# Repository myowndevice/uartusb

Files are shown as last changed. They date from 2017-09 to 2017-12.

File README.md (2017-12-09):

Данный репозитарий содержит информацию по прибору USB \ Serial
Если вы будете скачивать файлы через web не забудьте скачать общую папку Kicadlib

Если вы решили заняться электроникой, то вам просто необходим USB-Serial конвертер.
Вы его можете сделать самостоятельно по данной [инструкции](http://myowndevice.ru/index.php/pribory/item/7-usb-uart-konverter).

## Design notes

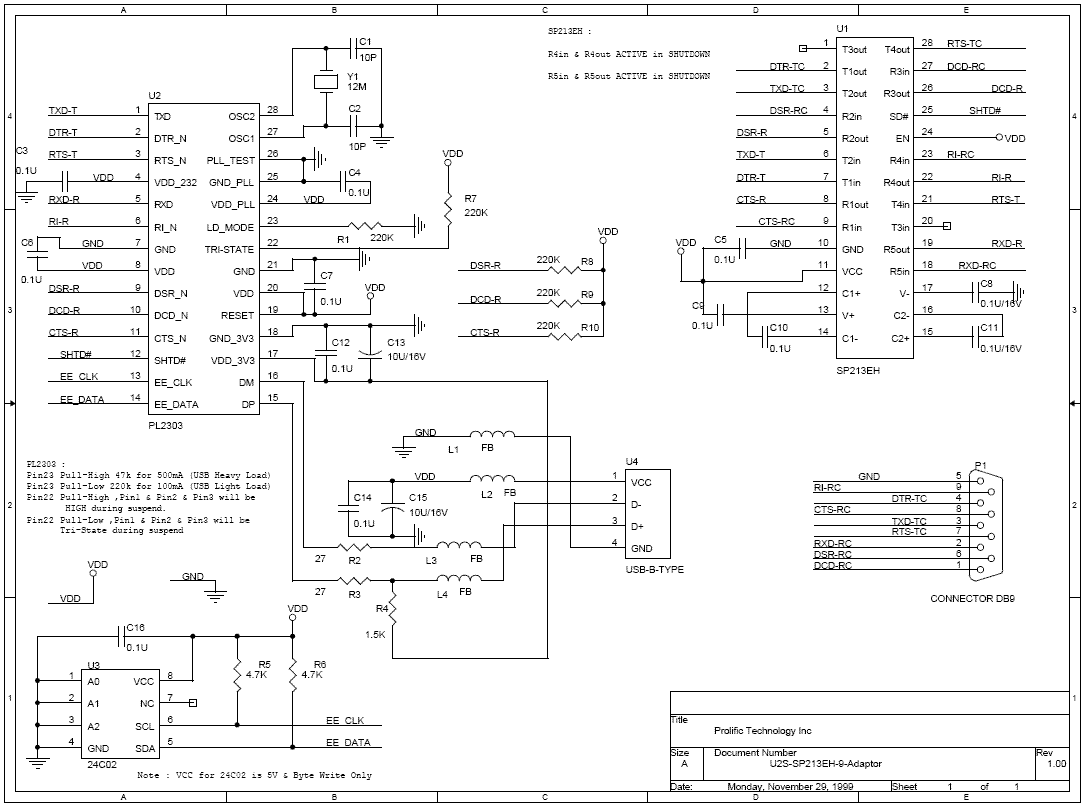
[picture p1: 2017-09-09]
datasheets/pl2303_75476858.gif

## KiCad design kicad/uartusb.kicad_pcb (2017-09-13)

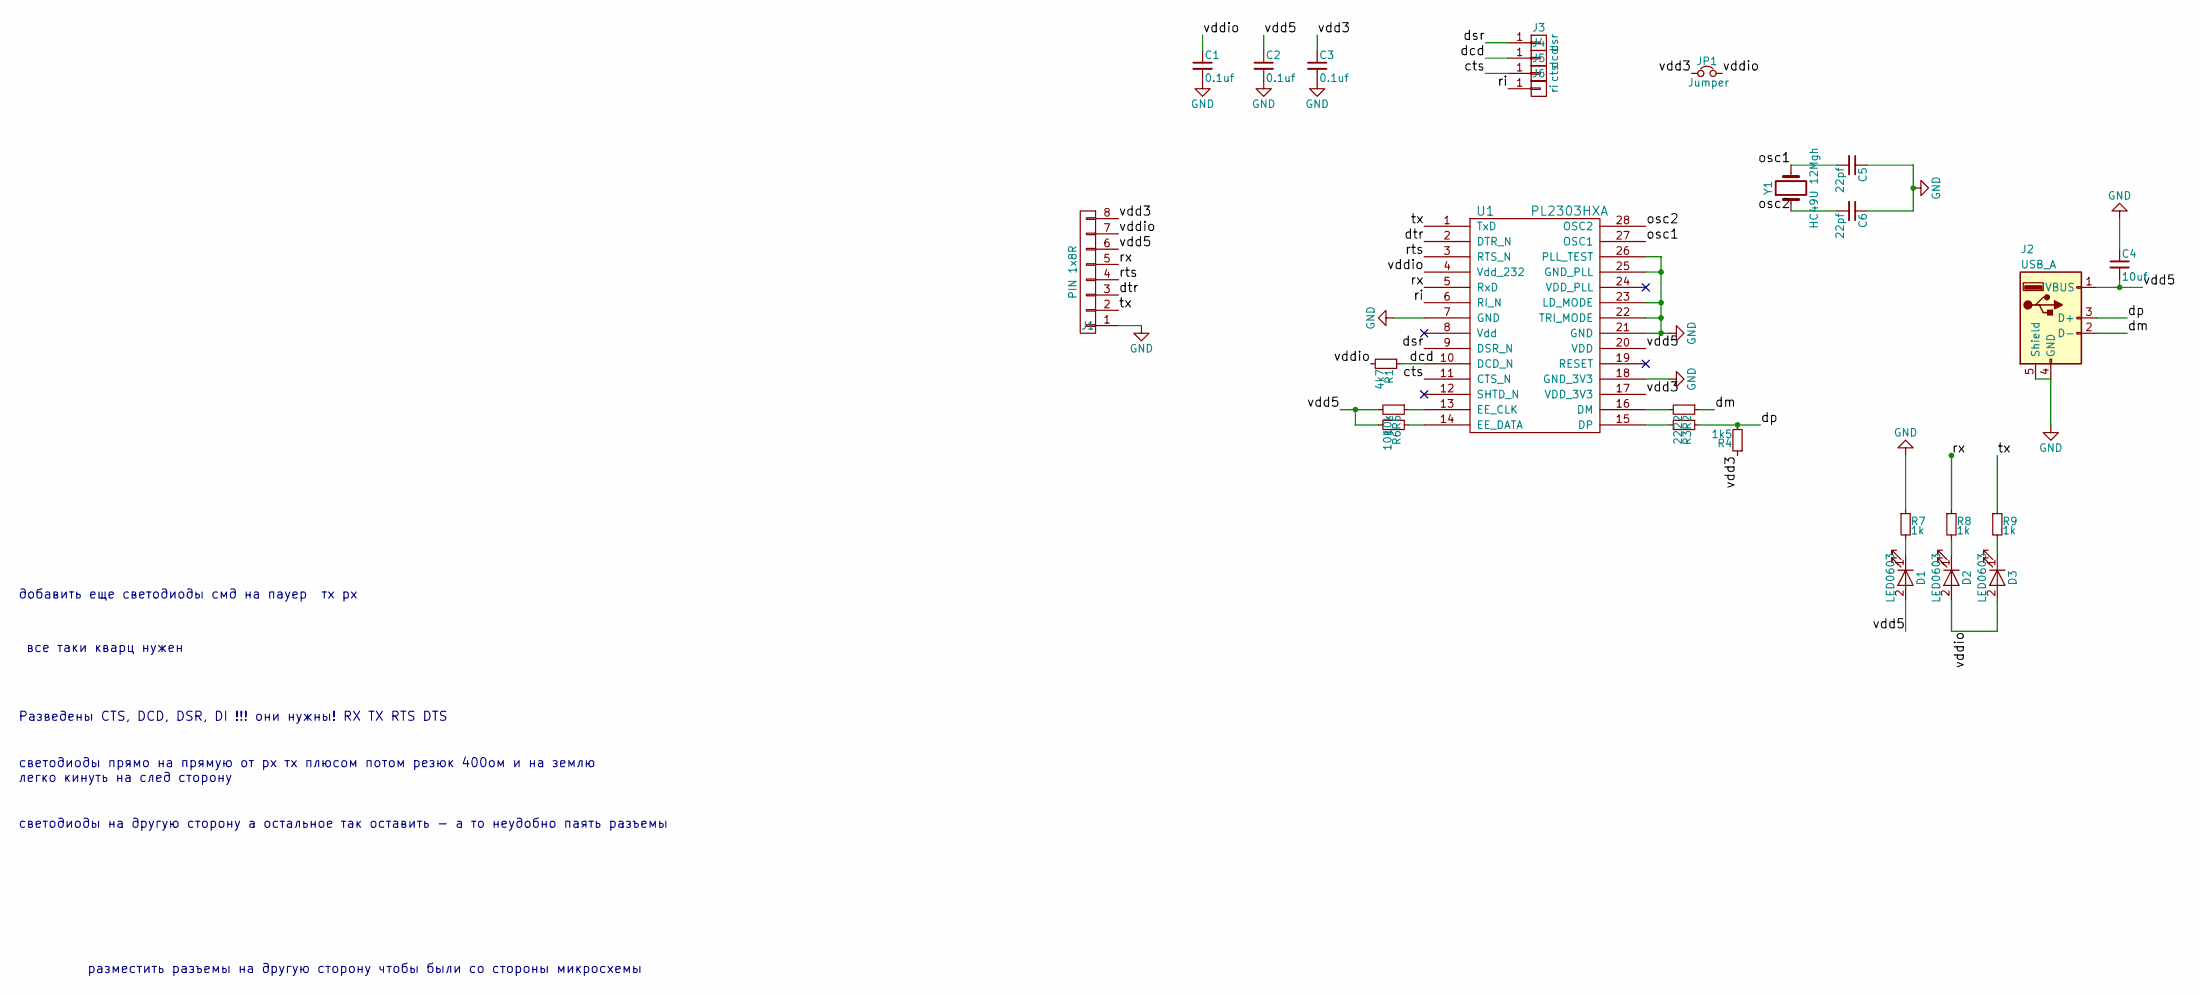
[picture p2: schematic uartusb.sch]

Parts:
C1, C2, C3: 0.1uf; C_0603_HandSoldering
C4: 10uf; R_0805_HandSoldering
C5, C6: 22pf; C_0603_HandSoldering
D1, D2, D3: LED0603; LED_0603_HandSoldering
J1: PIN 1x8R; Pin_Header_Angled_1x08_Pitch2.54mm
J2: USB_A; USB_A_male
J3: dsr; wirepadme
J4: dcd; wirepadme
J5: cts; wirepadme
J6: ri; wirepadme
JP1: Jumper; Pin_Header_Straight_1x02_Pitch2.54mm
R1: 4k7; R_0603_HandSoldering
R2, R3: 22; R_0603_HandSoldering
R4: 1k5; R_0603_HandSoldering
R5, R6: 10k; R_0603_HandSoldering
R7, R8, R9: 1k; R_0603_HandSoldering
U1: PL2303HXA; SSOP-28_5.3x10.2mm_Pitch0.65mm
Y1: HC49U 12Mgh; Crystal_HC49-4H_Vertical

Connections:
/cts: J5.1, U1.11 (CTS_N)
/dcd: J4.1, R1.1, U1.10 (DCD_N)
/dm: J2.2 (D-), R2.1
/dp: J2.3 (D+), R3.1, R4.2
/dsr: J3.1, U1.9 (DSR_N)
/dtr: J1.3, U1.2 (DTR_N)
/osc1: C5.2, U1.27 (OSC1), Y1.2
/osc2: C6.2, U1.28 (OSC2), Y1.1
/ri: J6.1, U1.6 (RI_N)
/rts: J1.4, U1.3 (RTS_N)
/rx: J1.5, R8.1, U1.5 (RxD)
/tx: J1.2, R9.1, U1.1 (TxD)
/vdd3: C3.1, J1.8, JP1.1, R4.1, U1.17 (VDD_3V3)
/vdd5: C2.1, C4.2, D1.2 (A), J1.6, J2.1 (VBUS), R5.2, R6.2, U1.20 (VDD)
/vddio: C1.1, D2.2 (A), D3.2 (A), J1.7, JP1.2, R1.2, U1.4 (Vdd_232)
GND: C1.2, C2.2, C3.2, C4.1, C5.1, C6.1, J1.1, J2.4 (GND), J2.5 (Shield), R7.1, U1.7 (GND), U1.18 (GND_3V3), U1.21 (GND), U1.22 (TRI_MODE), U1.23 (LD_MODE), U1.25 (GND_PLL), U1.26 (PLL_TEST)
unnamed: D1.1 (K), R7.2
unnamed: D2.1 (K), R8.2
unnamed: D3.1 (K), R9.2
unnamed: R2.2, U1.16 (DM)
unnamed: R3.2, U1.15 (DP)
unnamed: R5.1, U1.13 (EE_CLK)
unnamed: R6.1, U1.14 (EE_DATA)

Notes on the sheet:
добавить еще светодиоды смд на пауер тх рх
разместить разъемы на другую сторону чтобы были со стороны микросхемы
светодиоды на другую сторону а остальное так оставить - а то неудобно паять разъемы
светодиоды прямо на прямую от рх тх плюсом потом резюк 400ом и на землю легко кинуть на след сторону
все таки кварц нужен
Разведены CTS, DCD, DSR, DI !!! они нужны! RX TX RTS DTS

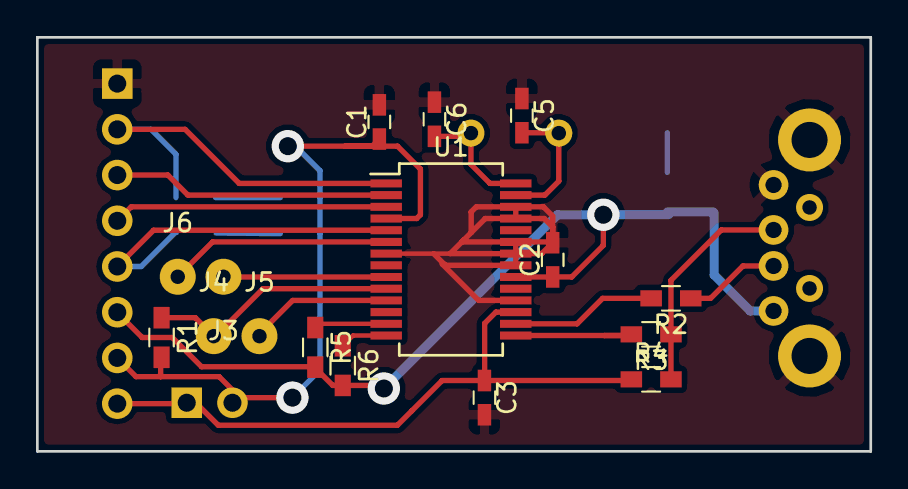
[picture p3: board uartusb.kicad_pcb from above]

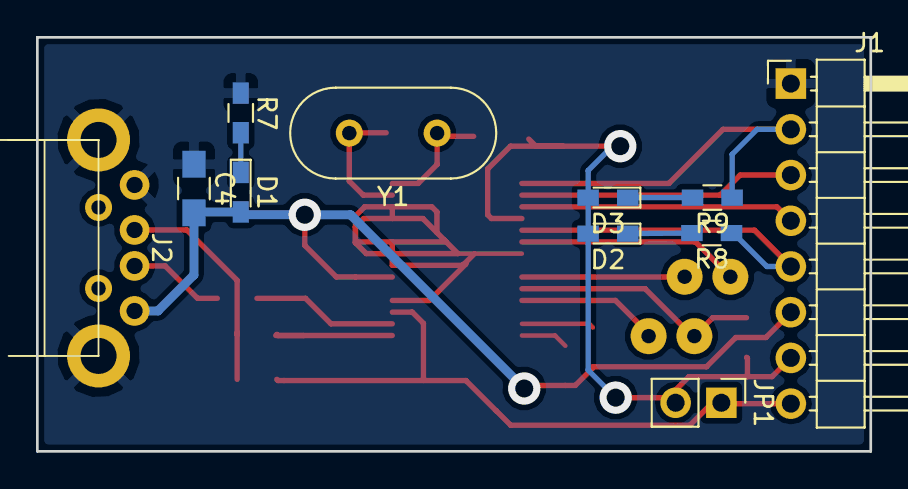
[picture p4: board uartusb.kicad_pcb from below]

Board: 2 copper layers, 46.3 x 23.0 mm, 27 parts (11 on the bottom side), 23 nets.
